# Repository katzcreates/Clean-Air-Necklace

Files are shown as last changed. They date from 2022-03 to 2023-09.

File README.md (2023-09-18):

# The Clean Air Necklace
Files and information for creating the Clean Air Necklace, both with the Design Spark Environmental Sensor Development Kit or with a commercially available particulate matter sensor. To see how the necklace was originally designed and built, check out the [full build video on YouTube](https://youtu.be/niAL5Nqm1jY).

There are two versions of this design that can be found in the 3D Models folder. The original design is V1, which is built to accomodate the Design Spark ESDK, and features slightly harder angles and edges in the necklace. The newer version, V2, features slightly softer edges in the necklace falls and is built to accomodate a commercial PM sensor. The designs can be mixed and matched if designed to use the newer design features with the ESDK, or the older design with the commercial PM sensor.

Both STEP and STL files can be found inside the 3D Models folder. Each STEP file contains all relevant models for that part of the project. Any adjustments to sizing or design changes can be made therein. Otherwise, for simple printing, individual STLs are provided, unsliced. One .3MF file has been provided for the clear top panels which is preset with the settings to create an alternating Hilbert Curve pattern for creating diffusion. Simply import the other top panel STLs into this file once opened to print with the same settings.

For the electronics components, virtually any microcontroller with an ESP32 enabled chip will do, as well as any addressable LEDs, but to take advantage of the compact electronics enclosure I designed as well as the code I wrote, I recommend the following components:

- [The Unexpected Maker TinyPICO V2](https://www.tinypico.com/)

- [144/metre Neopixel LED Strips](https://www.adafruit.com/product/1506)

- [Adafruit USB-C Breakout Board](https://www.adafruit.com/product/4090)

- [A simple Slide Switch](https://www.adafruit.com/product/805)

If going for the V2 build, a different microcontroller is required that can take hardware serial data in, which the Tiny Pico cannot do. As such, I recommend the following components for a V2 build:

- [Adafruit ItsyBitsy MO Express](https://www.adafruit.com/product/3727)

You will also need a particulate matter sensor for V2. The one used in my code and most readily available is the PMS5003:

- [PMS5003 Particulate Matter Sensor](https://shop.pimoroni.com/products/pms5003-particulate-matter-sensor-with-cable?variant=29075640352851)

Otherwise the components are the same. V2 does require a second slide switch to provide a way to switch because live data readings and the demo mode provided in the code.

The code provided for V1 will enable connection to WiFi, an MQTT broker hosted locally, and provide animations correspondant to PM 2.5 readings from a sensor. This is set up to work with the [DesignSpark ESDK](https://www.rs-online.com/designspark/introducing-the-environmental-sensor-development-kit). The code requires the FastLED library to function, which can be found [here](https://github.com/FastLED/FastLED). It is currently set up with two patterns; a base pattern when the PM levels are below a threshold, and an overlay for when PM levels exceed threshold. Additional patterns can be added to cycle through the base pattern easily within the code.

The code for V2 also uses FastLED libraries for the animation (which is functionally the same as V1) but is set up to receive data from the PMS5003 and work with a slide switch to choose between live readings and the demo mode. This version does not require WiFi to work.

The current PM threshold is set based on information set out by the US Environmental Protection agency, but are by no means definitive and can be altered to communicate data differently. Feel free to change the threshold within the code as you see fit.

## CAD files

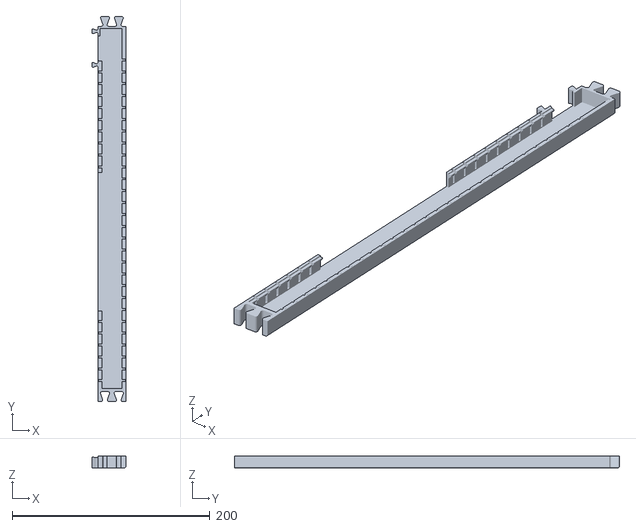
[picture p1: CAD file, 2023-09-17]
3D Models/STLs/CleanAirNecklace_V2_MainNecklaceBody.stl
34.4 x 388.9 x 12.0

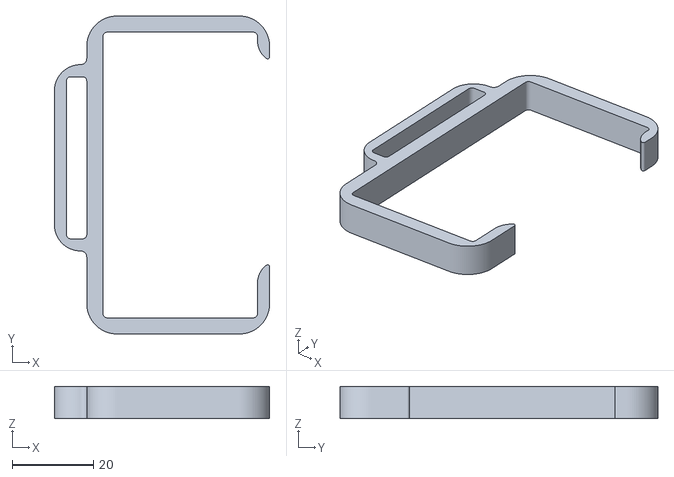
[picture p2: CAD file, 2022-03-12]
3D Models/STLs/ESDK_SensorMainBeltClip.stl
53.2 x 78.5 x 8.00

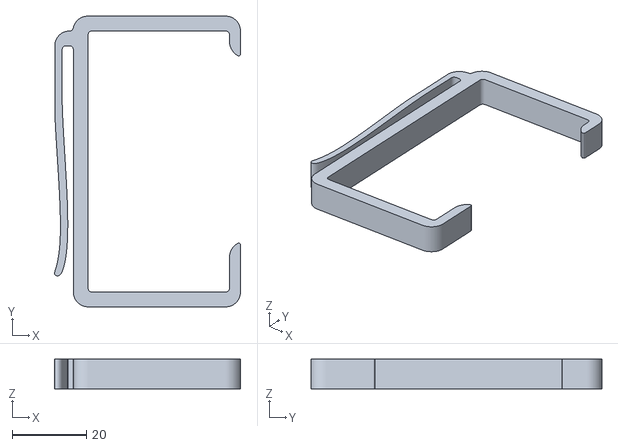
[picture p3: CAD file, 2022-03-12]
3D Models/STLs/ESDK_SensorMainPantClip.stl
50.2 x 78.5 x 8.00

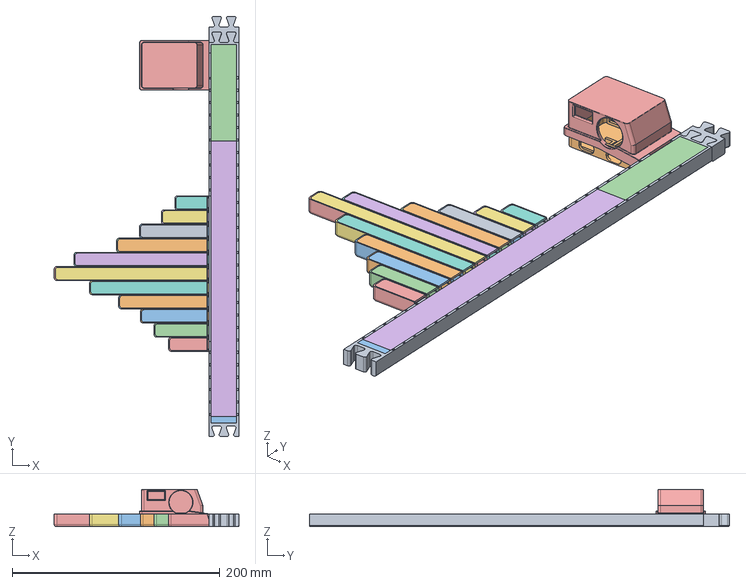
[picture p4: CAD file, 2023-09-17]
3D Models/CleanAirNecklaceV2_Components.step
177.5 x 403.9 x 36.0 mm

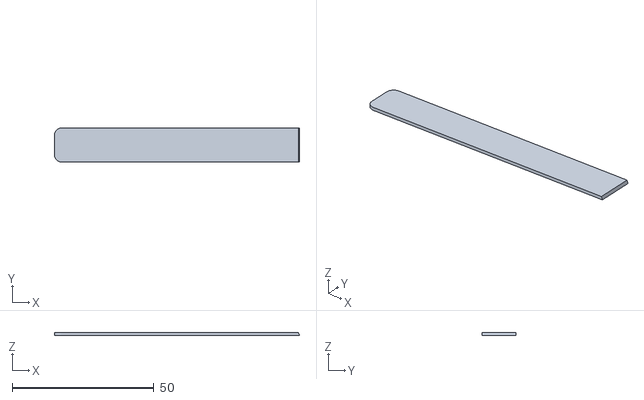
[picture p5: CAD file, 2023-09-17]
3D Models/STLs/CleanAirNecklace_V2_ClearCoverChannel04.stl
86.4 x 12.0 x 1.00

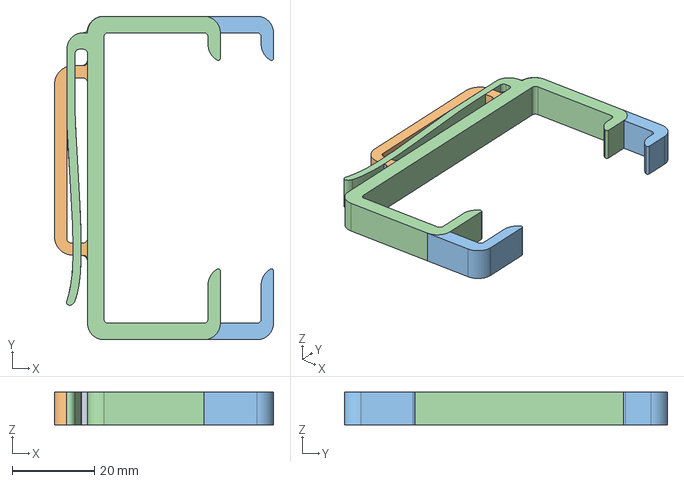
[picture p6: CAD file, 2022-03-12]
3D Models/ESDK_SensorClips.step
53.1 x 78.5 x 8.00 mm

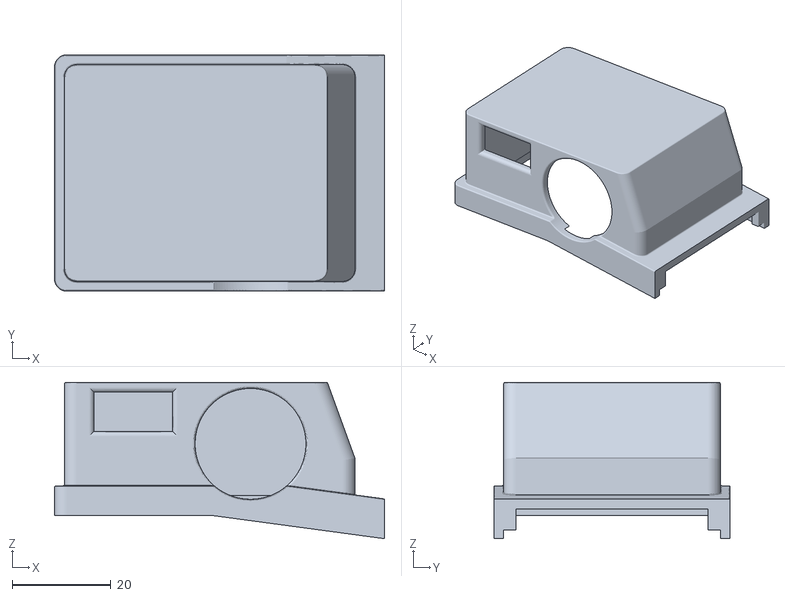
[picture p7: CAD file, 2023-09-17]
3D Models/STLs/CleanAirNecklace_V2_MCUEnclosureLid.stl
67.0 x 48.0 x 31.7

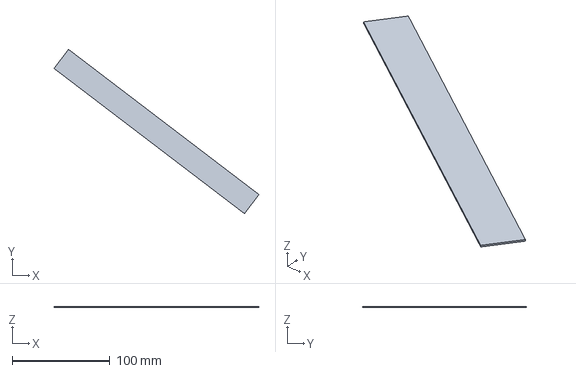
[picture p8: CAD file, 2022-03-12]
3D Models/DiffusionPanelSettings.3mf
209.7 x 168.0 x 1.00 mm

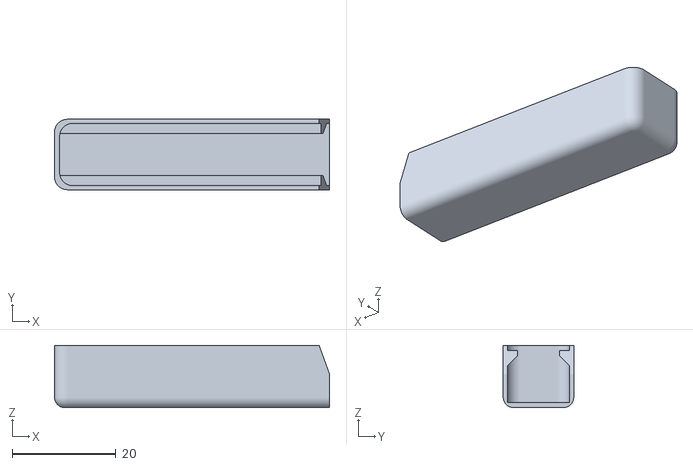
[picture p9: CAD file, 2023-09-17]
3D Models/STLs/CleanAirNecklace_V2_LEDChannel10.stl
53.0 x 13.6 x 12.0

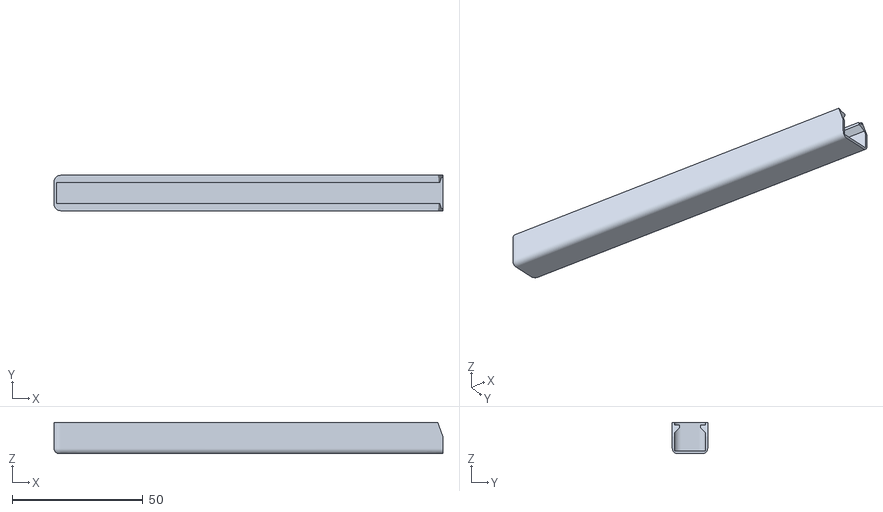
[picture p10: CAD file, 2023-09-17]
3D Models/STLs/CleanAirNecklace_V2_LEDChannel06.stl
149.0 x 13.6 x 12.0

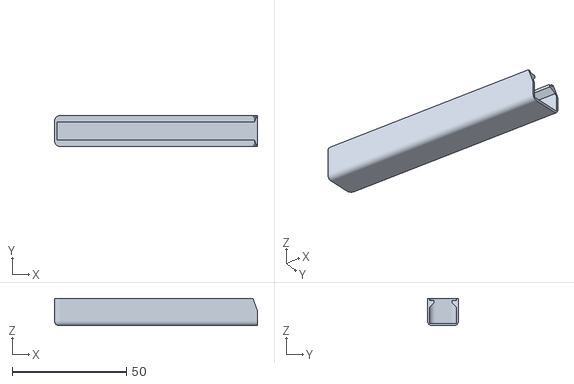
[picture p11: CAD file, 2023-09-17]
3D Models/STLs/CleanAirNecklace_V2_LEDChannel04.stl
89.0 x 13.6 x 12.0

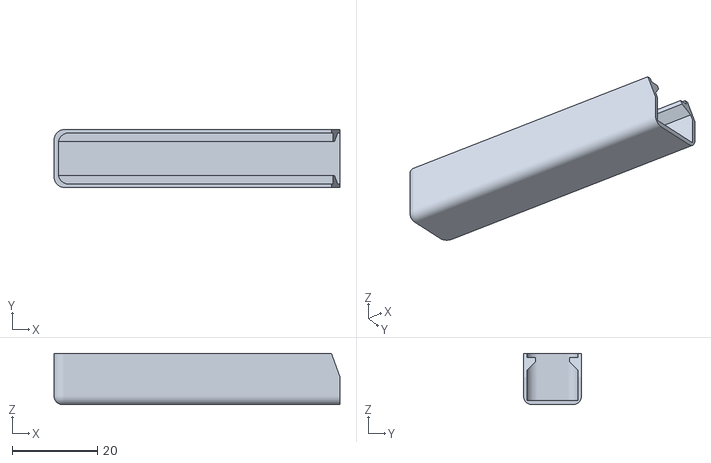
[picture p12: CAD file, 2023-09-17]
3D Models/STLs/CleanAirNecklace_V2_LEDChannel03.stl
67.0 x 13.6 x 12.0

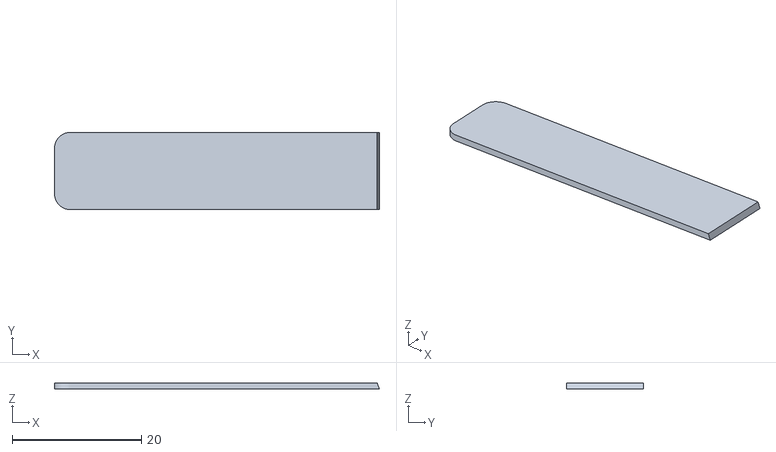
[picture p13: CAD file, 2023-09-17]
3D Models/STLs/CleanAirNecklace_V2_ClearCoverChannel10.stl
50.4 x 12.0 x 1.00

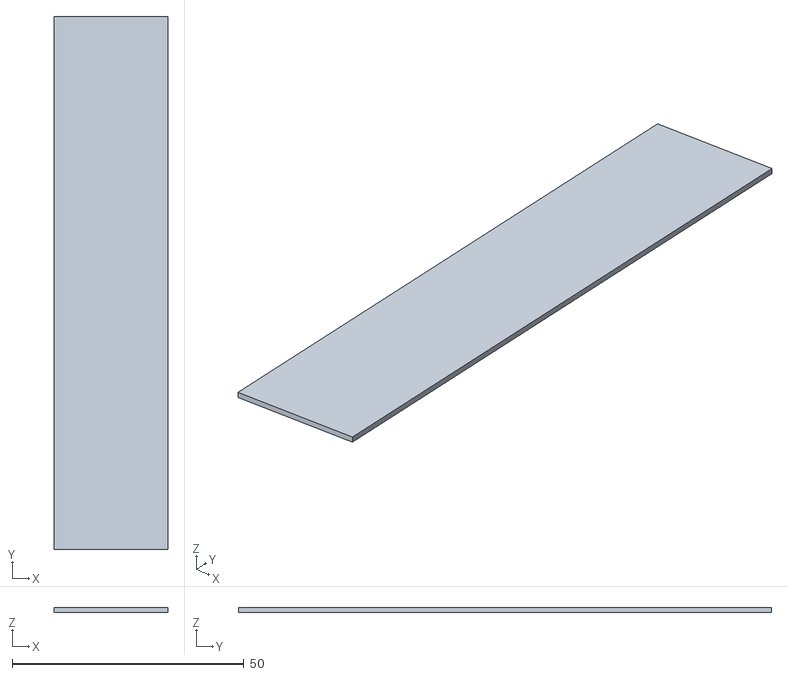
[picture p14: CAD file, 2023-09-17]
3D Models/STLs/CleanAirNecklace_V2_OpaqueCoverLeft.stl
24.5 x 115.0 x 1.00

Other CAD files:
3D Models/STLs/CleanAirNecklace_V2_ClearCoverChannel05.stl
3D Models/STLs/CleanAirNecklace_V2_ClearCoverChannel02.stl
3D Models/STLs/CleanAirNecklace_V2_LEDChannel01.stl
3D Models/STLs/CleanAirNecklace_V2_ClearCoverChannel03.stl
3D Models/CleanAirNecklaceV1_Components.step
3D Models/STLs/CleanAirNecklace_CircumferenceExtender.stl
3D Models/STLs/CleanAirNecklace_V1_ClearCover.stl
3D Models/STLs/CleanAirNecklace_V1_ClearCoverChannel01.stl
3D Models/STLs/CleanAirNecklace_V1_ClearCoverChannel02.stl
3D Models/STLs/CleanAirNecklace_V1_ClearCoverChannel03.stl
3D Models/STLs/CleanAirNecklace_V1_ClearCoverChannel04.stl
3D Models/STLs/CleanAirNecklace_V1_ClearCoverChannel05.stl
3D Models/STLs/CleanAirNecklace_V1_ClearCoverChannel06.stl
3D Models/STLs/CleanAirNecklace_V1_ClearCoverChannel07.stl
3D Models/STLs/CleanAirNecklace_V1_ClearCoverChannel08.stl
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

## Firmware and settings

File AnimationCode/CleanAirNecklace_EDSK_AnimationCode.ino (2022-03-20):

#include <PubSubClient.h>
#include <FastLED.h>
#include "secrets.h"
#include "ArduinoJson.h"

#define DEBUG

// Nano 33 IoT compatibility
#if defined(ARDUINO_ARCH_SAMD)
#include <WiFiNINA.h>
#define DATA_PIN 9
#else
#include <WiFi.h>
#define DATA_PIN 33
#endif

#define BRIGHTNESS 32 // Universal LED brightness override
#define NUM_LEDS 185
#define NUMBER_OF_STARS 36
#define PM_MAX 500  // Max PM value
#define PM_THRESHOLD 12

// Demo stuff
#define PM_INCREMENT 10 // Amount PM changes each interval
#define PM_INTERVAL 500 // Change PM every N milliseconds
#define NEC_CONNECTED 0  // Connected mode
#define NEC_DEMO 1  // Demo mode
#define PM_CYCLE_INTERVAL 30 // Cycle interval in seconds  
int mode = NEC_DEMO;  // Default to demo mode

CRGB leds[NUM_LEDS];
CRGB base[NUM_LEDS];
CRGB overlay[NUM_LEDS];

uint8_t colorIndex;
uint8_t pmColor;

uint8_t gCurrentPatternNumber = 0; // Index number of which pattern is current
uint8_t gHue = 0; // rotating "base color" used by many of the patterns

// Depending on your animation, you may find different kinds of mapping useful. I've provided two types here, used by the animation below. You can add your own or use that provided here.
// 0-255 XY maps
byte coordsX256[NUM_LEDS] = { 0, 36, 73, 109, 146, 182, 219, 255, 255, 219, 182, 146, 109, 73, 36, 0, 0, 36, 73, 109, 146, 182, 219, 255, 255, 219, 182, 146, 109, 73, 36, 0, 0, 36, 73, 109, 146, 182, 219, 255, 255, 219, 182, 146, 109, 73, 36, 0, 0, 36, 73, 109, 146, 182, 219, 255, 255, 219, 182, 146, 109, 73, 36, 0 };
byte coordsY256[NUM_LEDS] = { 0, 0, 0, 0, 0, 0, 0, 0, 36, 36, 36, 36, 36, 36, 36, 36, 73, 73, 73, 73, 73, 73, 73, 73, 109, 109, 109, 109, 109, 109, 109, 109, 146, 146, 146, 146, 146, 146, 146, 146, 182, 182, 182, 182, 182, 182, 182, 182, 219, 219, 219, 219, 219, 219, 219, 219, 255, 255, 255, 255, 255, 255, 255, 255 };

#define ARRAY_SIZE(A) (sizeof(A) / sizeof((A)[0]))

// XY maps
const byte LED_COLS = 33;
const byte LED_ROWS = 23;
const byte coordsX[NUM_LEDS] = { 0, 1, 2, 3, 4, 5, 6, 7, 8, 9, 10, 11, 12, 13, 14, 15, 16, 17, 18, 19, 20, 21, 22, 23, 24, 25, 26, 27, 28, 29, 30, 31, 32, 32, 31, 30, 29, 28, 27, 26, 25, 24, 23, 22, 21, 20, 19, 18, 17, 16, 15, 14, 13, 12, 11, 10, 9, 8, 7, 6, 5, 4, 3, 2, 1, 0, 26, 26, 26, 26, 26, 24, 24, 24, 24, 24, 24, 24, 22, 22, 22, 22, 22, 22, 22, 22, 22, 20, 20, 20, 20, 20, 20, 20, 20, 20, 20, 20, 20, 18, 18, 18, 18, 18, 18, 18, 18, 18, 18, 18, 18, 18, 18, 18, 18, 16, 16, 16, 16, 16, 16, 16, 16, 16, 16, 16, 16, 16, 16, 16, 16, 16, 16, 16, 16, 16, 14, 14, 14, 14, 14, 14, 14, 14, 14, 14, 14, 14, 14, 14, 14, 14, 14, 14, 12, 12, 12, 12, 12, 12, 12, 12, 12, 12, 12, 12, 10, 10, 10, 10, 10, 10, 10, 10, 10, 8, 8, 8, 8, 8, 8, 6, 6, 6, 6 };
const byte coordsY[NUM_LEDS] = { 22, 22, 22, 22, 22, 22, 22, 22, 22, 22, 22, 22, 22, 22, 22, 22, 22, 22, 22, 22, 22, 22, 22, 22, 22, 22, 22, 22, 22, 22, 22, 22, 21, 21, 21, 21, 21, 21, 21, 21, 21, 21, 21, 21, 21, 21, 21, 21, 21, 21, 21, 21, 21, 21, 21, 21, 21, 21, 21, 21, 21, 21, 21, 21, 21, 20, 19, 18, 17, 16, 20, 19, 18, 17, 16, 15, 14, 20, 19, 18, 17, 16, 15, 14, 13, 12, 20, 19, 18, 17, 16, 15, 14, 13, 12, 11, 10, 9, 20, 19, 18, 17, 16, 15, 14, 13, 12, 11, 10, 9, 8, 7, 6, 5, 20, 19, 18, 17, 16, 15, 14, 13, 12, 11, 10, 9, 8, 7, 6, 5, 4, 3, 2, 1, 0, 20, 19, 18, 17, 16, 15, 14, 13, 12, 11, 10, 9, 8, 7, 6, 5, 4, 3, 20, 19, 18, 17, 16, 15, 14, 13, 12, 11, 10, 9, 20, 19, 18, 17, 16, 15, 14, 13, 12, 20, 19, 18, 17, 16, 15, 20, 19, 18, 17, 22 };
const byte radii[] = { 128, 120, 112, 104, 96, 88, 80, 72, 64, 56, 48, 40, 32, 24, 16, 8, 1, 7, 15, 23, 31, 39, 47, 55, 63, 71, 79, 87, 95, 103, 111, 119, 127, 128, 120, 112, 104, 96, 88, 80, 72, 64, 56, 49, 41, 33, 26, 19, 14, 12, 14, 20, 27, 34, 42, 50, 57, 65, 73, 81, 89, 97, 105, 113, 121, 129, 83, 86, 92, 98, 105, 67, 72, 78, 86, 94, 103, 112, 53, 59, 66, 75, 84, 94, 104, 115, 125, 39, 47, 56, 66, 76, 87, 98, 109, 120, 131, 143, 154, 28, 38, 49, 60, 71, 83, 94, 105, 117, 128, 140, 151, 163, 175, 186, 198, 23, 35, 46, 58, 70, 81, 93, 104, 116, 128, 139, 151, 162, 174, 185, 197, 209, 220, 232, 243, 255, 28, 38, 49, 60, 71, 83, 94, 106, 117, 129, 140, 152, 163, 175, 186, 198, 209, 221, 40, 48, 57, 66, 77, 87, 98, 109, 120, 132, 143, 154, 54, 60, 67, 75, 85, 94, 105, 115, 126, 68, 73, 79, 87, 95, 103, 83, 87, 93, 99 };

byte gridIndexHorizontal(byte x, byte y) {
  for (byte i = 0; i < NUM_LEDS; i++) {
    if (coordsX[i] == x && coordsY[i] == y) {
      return i;
    }
  }
  return 255;
}

// ESDK MQTT Connection
//const char broker[] = "255.255.255.255"; // Replace with the local IP of your sensor
const char broker[] = "airquality";
int        port     = 1883;
#define TOPIC "airquality/#"

// Wifi Connection
// I recommend creating your own secrets.h file to keep your connection information secure!

char ssid[] = SECRET_SSID;  // Network SSID // Use info from secrets.h or place your own SSID here
char pass[] = SECRET_PASS;  // WPA key // Use info from secrets.h or place your own password here

WiFiClient wifiClient;
long lastReconnectWIFIAttempt = 0;
PubSubClient mqttClient(wifiClient);
long lastReconnectMQTTAttempt = 0;

int wifiState = WL_IDLE_STATUS;


// ESDK Sensor Data
// Please see the ESDK documentation for more information and data options

//int co2 = 0;
//double temperature = 0;
//double humidity = 0;
//int tvoc = 0;
int pm = 0;

// Custom FastLED Palette
DEFINE_GRADIENT_PALETTE( warning_p ) {
  0, 255, 249, 155,
  60, 255, 102, 0,
  120, 255, 102,  0,
  180,  255,  0,  0,
  220, 217, 5, 102,
  255, 149, 0, 46
};

CRGBPalette16 myPal = warning_p;



// Bad Air Sparks Animation
class Star {
  public:
    float z;
    float startY;
    float y;
    float x;
    unsigned long startTime;
    int hue;
    int saturation;



    void restart() {
      z = random(1, 4);
      y = 0;
      hue = pmColor;
      // saturation = 80 + 128 / z;
      saturation = 255 - (z - 1) * 50;
      startY = y;
      x = random(0, LED_COLS);
      startTime = millis();
      pm = constrain(pm, 0, PM_MAX);
      colorIndex = map(pm, PM_THRESHOLD, PM_MAX, 0, 240); 
      pmColor = ColorFromPalette(myPal, colorIndex, LINEARBLEND);
    }

    void start() {
      restart();
      y = 0;
      startY = y;
    }

    void move() {
      unsigned long age = millis() - startTime;
      float speed = z * 10;
      y = startY + age / 2300.0 * speed;

      hue++;

      if (isDead())
        restart();
    }

    bool isDead() {
      return x < 0 || x >= LED_COLS || y < 0 || y >= LED_ROWS;
    }

    float length() {
      return 3 + z * 5;
    }

    float brightness() {
      return 0.2 + 0.4 * (z - 1);
    }
};

namespace Starfield {
Star stars[NUMBER_OF_STARS] = {};
bool setup = false;

void drawStar(Star star) {
  int16_t index = gridIndexHorizontal(star.x, star.y);
  float length = star.length();
  int radius = 5;

  // 20% + brightness / 80%
  // float brightnessFactor = (star.z / 3.0) * 0.9 + 0.1;
  // float brightnessFactor = 0.1 + 0.3 * star.z -;
  float brightnessFactor = star.brightness();

  int x = star.x;
  double startY = star.y;
  int lowY = floor(startY) - radius;
  int ceilY = ceil(startY) + radius;

  int headLength = 2;
  for (int y = startY - headLength; y <= ceilY; y++) {
    if (y < 0 || y >= LED_ROWS) continue;

    int16_t index = gridIndexHorizontal(x, y);
    if (index >= NUM_LEDS)
      continue;

    double distance = (fabs(y - startY) - 0.5) / headLength;
    if (distance < 0) {
      leds[index] += ColorFromPalette(myPal, colorIndex, 255.0 * brightnessFactor);
    } else if (distance > 1) {} else {
      int brightness = 255 - distance * 255.0;
      leds[index] += ColorFromPalette(myPal, colorIndex, brightness * brightnessFactor);
    }
  }

  // Tail
  int tailLength = length;
  for (int y = startY; y >= startY - tailLength; y--) {
    if (y < 0 || y >= LED_ROWS) continue;

    int16_t index = gridIndexHorizontal(x, y);
    if (index >= NUM_LEDS)
      continue;

    double distance = (fabs(y - startY) - 0.5) / tailLength;
    if (distance < 0) {
      leds[index] += ColorFromPalette(myPal, colorIndex, 255.0 * brightnessFactor);
    } else if (distance > 1) {} else {
      int brightness = 255 - distance * 255.0;
      leds[index] += ColorFromPalette(myPal, colorIndex, brightness * brightnessFactor);
    }
  }
}

void draw() {
  if (!setup) {
    setup = true;
    for (int i = 0; i < NUMBER_OF_STARS; i++) {
      stars[i].start();
    }
  }

  for (int i = 0; i < NUMBER_OF_STARS; i++) {
    stars[i].move();
    drawStar(stars[i]);
  }
}
}

void setup() {
  Serial.begin(115200);
#ifdef DEBUG
  while (!Serial) {
    ; // wait for serial port to connect
  }
  Serial.println("Starting Clean Air Necklace");
#endif
  delay(10);

  // We start by connecting to a WiFi network
  // WL_IDLE_STATUS     = 0
  // WL_NO_SSID_AVAIL   = 1
  // WL_SCAN_COMPLETED  = 2
  // WL_CONNECTED       = 3
  // WL_CONNECT_FAILED  = 4
  // WL_CONNECTION_LOST = 5
  // WL_DISCONNECTED    = 6
  Serial.println();
  Serial.print("Connecting to ");
  Serial.println(ssid);

  WiFi.begin(ssid, pass);

  while (WiFi.status() != WL_CONNECTED) {
    delay(500);
    Serial.println(WiFi.status());
    if ((WiFi.status() == WL_CONNECT_FAILED) || (WiFi.status() == WL_NO_SSID_AVAIL)) {
      mode = NEC_DEMO;
      Serial.println("Entering demo mode");
      break;
    }
    Serial.print(".");
  }

  if (WiFi.status() == WL_CONNECTED) {
    mode = NEC_CONNECTED;
    Serial.println("Entering connected mode");
    Serial.println("IP address: ");
    Serial.println(WiFi.localIP());

    mqttClient.setServer(broker, port);
    mqttClient.setCallback(callback);
    mqttClient.setBufferSize(384);
  }

  FastLED.addLeds<NEOPIXEL, DATA_PIN>(leds, NUM_LEDS);
  FastLED.setBrightness(BRIGHTNESS);
  FastLED.clear();
}

// Base Animation Patterns get set here! Add your own if you want!

void outwardOcean() {
  for (uint16_t i = 0; i < NUM_LEDS; i++) {
    leds[i] = ColorFromPalette(OceanColors_p, radii[i] - gHue);
  }
}

typedef void (*SimplePatternList[])();
SimplePatternList gPatterns = {
  outwardOcean
};

void nextPattern()
{
  // add one to the current pattern number, and wrap around at the end
  gCurrentPatternNumber = (gCurrentPatternNumber + 1) % ARRAY_SIZE( gPatterns);
}

int pm_cycle = 0;

void loop()
{
  FastLED.show();

  switch (mode) {
    // Do connected stuff
    case NEC_CONNECTED:
      if (WiFi.status() != WL_CONNECTED) {
        reconnectWiFi();
      }

      if (!mqttClient.connected()) {
        // Attempt to reconnect without blocking
        long now = millis();
        if (now - lastReconnectMQTTAttempt > 5000) {
          lastReconnectMQTTAttempt = now;
          if (reconnectMQTT()) {
            lastReconnectMQTTAttempt = 0;
          }
        }
      }
      else {
        mqttClient.loop();
      }
      break;

    // Do demo stuff
    case NEC_DEMO:
      changePmCycle(PM_CYCLE_INTERVAL);
      switch (pm_cycle) {
        case 0:
          pm = 1;
          break;
        case 1:
          incPM(PM_INTERVAL, PM_INCREMENT);
          break;
        case 2:
          decPM(PM_INTERVAL, PM_INCREMENT);
          break;
      }
  }
#ifdef DEBUG
  // This can be used to help debug problems with the sensor connection if needed.
  EVERY_N_SECONDS(1) {
    Serial.print("PM2.5: ");
    Serial.print(pm);
    Serial.println();
  }
#endif
  basePattern();
  overlayPattern();
  combinePatterns();
}  // end loop


// Change PM cycle every interval (demo mode)
void changePmCycle(int interval) {
  EVERY_N_SECONDS(interval) {
    pm_cycle++;
    if (pm_cycle > 2) {
      pm_cycle = 0;
    }
  }
}

// Increment PM every interval (demo mode)
void incPM(int interval, int increment) {
  if (pm < PM_MAX) {
    EVERY_N_MILLISECONDS(interval) {
      pm += increment;
    }
  }
  else {  // Hold at max pm
    pm = PM_MAX;
  }
}

// Decrement PM every interval (demo mode)
void decPM(int interval, int increment) {
  if (pm < 1) { // Hold at 1
    pm = 1;
  }
  else {
    EVERY_N_MILLISECONDS(interval) {
      pm -= increment;
    }
  }
}

void basePattern() {
  gPatterns[gCurrentPatternNumber]();

  EVERY_N_MILLISECONDS( 20 ) {
    gHue++;  // slowly cycle the "base color" through the rainbow
  }

  EVERY_N_SECONDS( 10 ) {
    nextPattern();  // change patterns periodically
  }

}//end_basePattern

int fadeAmount1 = 0;
int fadeAmount2 = 0;
int maxFadeAmount1 = 255;
int maxFadeAmount2 = 255;

void overlayPattern() {  // This is where the Sparks animation gets triggered if the PM levels are above threshold
  if (pm > PM_THRESHOLD) {

    fadeToBlackBy( leds, NUM_LEDS, fadeAmount1);

    EVERY_N_MILLISECONDS(30) {
      if (fadeAmount1 < maxFadeAmount1) {
        fadeAmount1++;
      }
    }



    EVERY_N_MILLIS(30) {
      gHue++;
    }

    Starfield::draw();
  }


  else {  //overlay is currently "Off"
    fadeToBlackBy( leds, NUM_LEDS, fadeAmount1);
    EVERY_N_MILLISECONDS(20) {
      if (fadeAmount1 > 0) {
        fadeAmount1--;
      }
    }
    fadeToBlackBy( overlay, NUM_LEDS, fadeAmount2);
    EVERY_N_MILLISECONDS(30) {
      if (fadeAmount2 < maxFadeAmount2) {
        fadeAmount2++;  //fadeout overlay pattern
      }
    }
  }
}

void combinePatterns() {
  for (uint8_t i = 0; i < NUM_LEDS; i++) {
    leds[i] += overlay[i];  //add overlay to leds
  }
}

// Connecting to a WiFi network
void reconnectWiFi() {
#ifdef DEBUG
  Serial.print("Wifi Status: ");
  Serial.println(WiFi.status());
  Serial.print("Trying connection to ");
  Serial.println(ssid);
#endif
  WiFi.disconnect();
  delay(10000);
  wifiState = WiFi.begin(ssid, pass);
}

boolean reconnectMQTT() {
  Serial.print("Attempting connection to MQTT broker: ");
  Serial.println(broker);
  if (mqttClient.connect("necklaceClient")) {
    mqttClient.subscribe("airquality/#");
    Serial.println("MQTT connected");
  }
  return mqttClient.connected();
}

void callback(char* topic, byte * payload, unsigned int length) {
#ifdef DEBUG
  Serial.println("Message");
  //  Serial.print("Message arrived [");
  //  Serial.print(topic);
  //  Serial.print("] ");
  //  for (int i = 0; i < length; i++) {
  //    Serial.print((char)payload[i]);
  //  }
  //  Serial.println();
#endif
  // ESDK sends a large JSON payload
  // - ensure you have enough memory allocated
  StaticJsonDocument<384> doc;
  deserializeJson(doc, payload, length);
  // Unused ESDK values
  //  co2 = doc["co2"]["co2"];
  //  temperature = doc["thv"]["temperature"];
  //  humidity = doc["thv"]["humidity"];
  //  tvoc = doc["thv"]["vocIndex"];
  pm = doc["pm"]["pm2.5"];



}

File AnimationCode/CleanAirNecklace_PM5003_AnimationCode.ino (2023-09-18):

#include <FastLED.h>

//#define DEBUG 1

#define DATA_PIN 5 // Pinout for the LEDs
const int DEMO_SWITCH = 15; // A slide switch used to turn demo mode on and off
#define BRIGHTNESS 100
#define NUM_LEDS 185
#define PM_INCREMENT_REGULAR 1   // Increment for regular PM change
#define PM_MAX 350               // Max PM value
#define PM_MAX_SLOW 16           // Max PM value for slow change
#define PM_INCREMENT_SLOW 1     // Increment for slow PM change (in 1/100 units)


CRGB leds[NUM_LEDS];
CRGB base[NUM_LEDS];
CRGB overlay[NUM_LEDS];

uint8_t colorIndex;
uint8_t pmColor;


uint8_t gCurrentPatternNumber = 0; // Index number of which pattern is current
uint8_t gHue = 0; // rotating "base color" used by many of the patterns

#define ARRAY_SIZE(A) (sizeof(A) / sizeof((A)[0]))

// XY maps
const byte LED_COLS = 33;
const byte LED_ROWS = 23;

byte coordsX[NUM_LEDS] = { 0, 1, 2, 3, 4, 5, 6, 7, 8, 9, 10, 11, 12, 13, 14, 15, 16, 17, 18, 19, 20, 21, 22, 23, 24, 25, 26, 27, 28, 29, 30, 31, 32, 32, 31, 30, 29, 28, 27, 26, 25, 24, 23, 22, 21, 20, 19, 18, 17, 16, 15, 14, 13, 12, 11, 10, 9, 8, 7, 6, 5, 4, 3, 2, 1, 0, 6, 6, 6, 6, 6, 8, 8, 8, 8, 8, 8, 8, 10, 10, 10, 10, 10, 10, 10, 10, 10, 12, 12, 12, 12, 12, 12, 12, 12, 12, 12, 12, 12, 14, 14, 14, 14, 14, 14, 14, 14, 14, 14, 14, 14, 14, 14, 14, 14, 16, 16, 16, 16, 16, 16, 16, 16, 16, 16, 16, 16, 16, 16, 16, 16, 16, 16, 16, 16, 16, 18, 18, 18, 18, 18, 18, 18, 18, 18, 18, 18, 18, 18, 18, 18, 18, 18, 18, 20, 20, 20, 20, 20, 20, 20, 20, 20, 20, 20, 20, 22, 22, 22, 22, 22, 22, 22, 22, 22, 24, 24, 24, 24, 24, 24, 26, 26, 26, 26 };
const byte coordsY[NUM_LEDS] = { 22, 22, 22, 22, 22, 22, 22, 22, 22, 22, 22, 22, 22, 22, 22, 22, 22, 22, 22, 22, 22, 22, 22, 22, 22, 22, 22, 22, 22, 22, 22, 22, 22, 21, 21, 21, 21, 21, 21, 21, 21, 21, 21, 21, 21, 21, 21, 21, 21, 21, 21, 21, 21, 21, 21, 21, 21, 21, 21, 21, 21, 21, 21, 21, 21, 21, 20, 19, 18, 17, 16, 20, 19, 18, 17, 16, 15, 14, 20, 19, 18, 17, 16, 15, 14, 13, 12, 20, 19, 18, 17, 16, 15, 14, 13, 12, 11, 10, 9, 20, 19, 18, 17, 16, 15, 14, 13, 12, 11, 10, 9, 8, 7, 6, 5, 20, 19, 18, 17, 16, 15, 14, 13, 12, 11, 10, 9, 8, 7, 6, 5, 4, 3, 2, 1, 0, 20, 19, 18, 17, 16, 15, 14, 13, 12, 11, 10, 9, 8, 7, 6, 5, 4, 3, 20, 19, 18, 17, 16, 15, 14, 13, 12, 11, 10, 9, 20, 19, 18, 17, 16, 15, 14, 13, 12, 20, 19, 18, 17, 16, 15, 20, 19, 18, 17 };
byte angles[NUM_LEDS] = { 0, 0, 0, 0, 0, 0, 0, 0, 0, 0, 0, 0, 0, 0, 0, 0, 0, 128, 128, 128, 128, 128, 128, 128, 128, 128, 128, 128, 128, 128, 128, 128, 128, 130, 130, 130, 131, 131, 131, 132, 132, 133, 133, 134, 136, 137, 141, 146, 159, 191, 223, 236, 242, 245, 247, 248, 249, 250, 251, 251, 251, 252, 252, 252, 252, 252, 247, 243, 240, 236, 233, 245, 240, 236, 232, 229, 226, 223, 242, 236, 231, 227, 223, 220, 217, 215, 213, 236, 229, 223, 219, 215, 212, 210, 208, 207, 205, 204, 203, 223, 215, 210, 207, 204, 203, 201, 200, 199, 199, 198, 197, 197, 197, 196, 196, 191, 191, 191, 191, 191, 191, 191, 191, 191, 191, 191, 191, 191, 191, 191, 191, 191, 191, 191, 191, 191, 159, 167, 172, 176, 178, 180, 181, 182, 183, 184, 185, 185, 185, 186, 186, 186, 187, 187, 146, 154, 159, 164, 167, 170, 172, 174, 176, 177, 178, 179, 141, 146, 151, 156, 159, 162, 165, 167, 169, 137, 142, 146, 150, 154, 157, 136, 139, 143, 146 };
byte radii[NUM_LEDS] = { 185, 174, 162, 151, 139, 128, 116, 104, 93, 81, 70, 58, 46, 35, 23, 12, 0, 12, 23, 35, 46, 58, 70, 81, 93, 104, 116, 128, 139, 151, 162, 174, 185, 186, 174, 163, 151, 140, 128, 116, 105, 93, 82, 71, 59, 48, 37, 26, 16, 12, 16, 26, 37, 48, 59, 71, 82, 93, 105, 116, 128, 140, 151, 163, 174, 186, 118, 121, 125, 130, 135, 96, 99, 104, 109, 116, 123, 131, 73, 78, 84, 91, 98, 107, 116, 125, 135, 52, 58, 66, 74, 84, 93, 104, 114, 125, 136, 147, 158, 33, 42, 52, 62, 73, 84, 96, 107, 118, 130, 141, 152, 164, 175, 187, 198, 23, 35, 46, 58, 70, 81, 93, 104, 116, 128, 139, 151, 162, 174, 185, 197, 209, 220, 232, 243, 255, 33, 42, 52, 62, 73, 84, 96, 107, 118, 130, 141, 152, 164, 175, 187, 198, 210, 221, 52, 58, 66, 74, 84, 93, 104, 114, 125, 136, 147, 158, 73, 78, 84, 91, 98, 107, 116, 125, 135, 96, 99, 104, 109, 116, 123, 118, 121, 125, 130 };

byte gridIndexHorizontal(byte x, byte y) {
  for (byte i = 0; i < NUM_LEDS; i++) {
    if (coordsX[i] == x && coordsY[i] == y) {
      return i;
    }
  }
  return 255;
}
struct pms5003data {
  uint16_t framelen;
  uint16_t pm10_standard, pm25_standard, pm100_standard;
  uint16_t pm10_env, pm25_env, pm100_env;
  uint16_t particles_03um, particles_05um, particles_10um, particles_25um, particles_50um, particles_100um;
  uint16_t unused;
  uint16_t checksum;
};
 
struct pms5003data data;

int pm = 0;
int threshold = 12;

unsigned long lastUpdateTime = 0;  // Time when PM value was last updated
unsigned long updateInterval = 50; // Time interval (in milliseconds) between PM value updates

int pm_whole = 0;     // Whole part of PM value
int pm_fraction = 0;  // Fractional part of PM value (in 1/100 units)

unsigned long slowUpdateTime = 0; // Time when PM value was last updated (below PM_MAX_SLOW)
unsigned long slowUpdateInterval = 5; // Time interval (in milliseconds) between PM value updates (below PM_MAX_SLOW)


DEFINE_GRADIENT_PALETTE( warning_p ) {
  0, 255, 253, 225,
  30, 255, 248, 0,
  120, 255, 102,  0,
  205,  255,  0,  0,
  229, 217, 5, 102,
  255, 149, 0, 133
};



CRGBPalette16 myPal = warning_p;




class Star {
  public:
    float z;
    float startY;
    float y;
    float x;
    unsigned long startTime;
    int hue;
    int saturation;



    void restart() {
      z = random(1, 4);
      y = 0;
      hue = pmColor;
      // saturation = 80 + 128 / z;
      saturation = 255 - (z - 1) * 50;
      startY = y;
      x = random(0, LED_COLS);
      startTime = millis();
      pm = constrain(pm, 0, PM_MAX);
      colorIndex = map(pm, threshold, PM_MAX, 0, 240);
      pmColor = ColorFromPalette(myPal, colorIndex, LINEARBLEND);

    }

    void start() {
      restart();
      y = 0;
      startY = y;
    }

    void move() {
      unsigned long age = millis() - startTime;
      float speed = z * 10;
      y = startY + age / 2500.0 * speed;

      hue++;

      if (isDead())
        restart();
    }

    bool isDead() {
      return x < 0 || x >= LED_COLS || y < 0 || y >= LED_ROWS;
    }

    float length() {
      return 3 + z * 5;
    }

    float brightness() {
      return 0.2 + 0.4 * (z - 1);
    }
};

#define NUMBER_OF_STARS 36

namespace Starfield {
Star stars[NUMBER_OF_STARS] = {};
bool setup = false;
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

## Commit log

2022-03-12 Added ESDK Sensor Clips
    [ESDK_SensorAddOnBeltClip.stl, ESDK_SensorAddOnPantClip.stl, ESDK_SensorClips.step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]
2023-09-17 Added V2 STL files and renamed V1 files
    [CleanAirNecklaceV1_Components.step, CleanAirNecklaceV2_Components.step, CleanAirNecklace_V1_ClearCover.stl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]
